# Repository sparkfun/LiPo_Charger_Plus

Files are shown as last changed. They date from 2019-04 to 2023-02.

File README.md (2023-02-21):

SparkFun LiPo Charger Plus
========================================

SparkFun LiPo Charger Plus

[*SparkFun LiPo Charger Plus (PRT-15217)*](https://www.sparkfun.com/products/15217)

The SparkFun LiPo Charger Plus is the souped-up power option in the SparkFun line of single-cell lithium polymer (LiPo) battery chargers. With this iteration, we've changed the input charge connector to USB-C and provided charge rate selection as well as optional thermal protection. Charge, power, and done LEDs clearly indicate the status of your charging process. This board can be used for any of the 2-pin JST connector single cell LiPo batteries we carry. 

With an input voltage between 3.75V-6V, the MCP73833 can charge up to a maximum rate of 1000mAh and provides two forms of thermal protection. An internal sensor maintains maximum charging rate until the die temperature of the IC reaches ~95°C; the charge controller will then reduce the charge rate to prevent overheating. The MCP73833 also has an optional input pin for an NTC (negative-temperature coefficient) thermistor, thus gating the battery against possible damage. 

Repository Contents
-------------------

* **/Hardware** - Eagle design files (.brd, .sch)

Documentation
--------------
* **[SparkFun Fritzing Part](https://github.com/sparkfun/Fritzing_Parts/blob/main/products/15217_sfe_LiPo_Charger_Plus.fzpz)** - Fritzing diagrams for SparkFun products.
* **[Hookup Guide](https://learn.sparkfun.com/tutorials/lipo-charger-plus-hookup-guide)** - Basic hookup guide for the SparkFun LiPo Charger Plus.

License Information
-------------------

This product is _**open source**_!

Please review the LICENSE.md file for license information.

If you have any questions or concerns on licensing, please contact technical support on our [SparkFun forums](https://forum.sparkfun.com/viewforum.php?f=152).

Distributed as-is; no warranty is given.

- Your friends at SparkFun.

_<COLLABORATION CREDIT>_

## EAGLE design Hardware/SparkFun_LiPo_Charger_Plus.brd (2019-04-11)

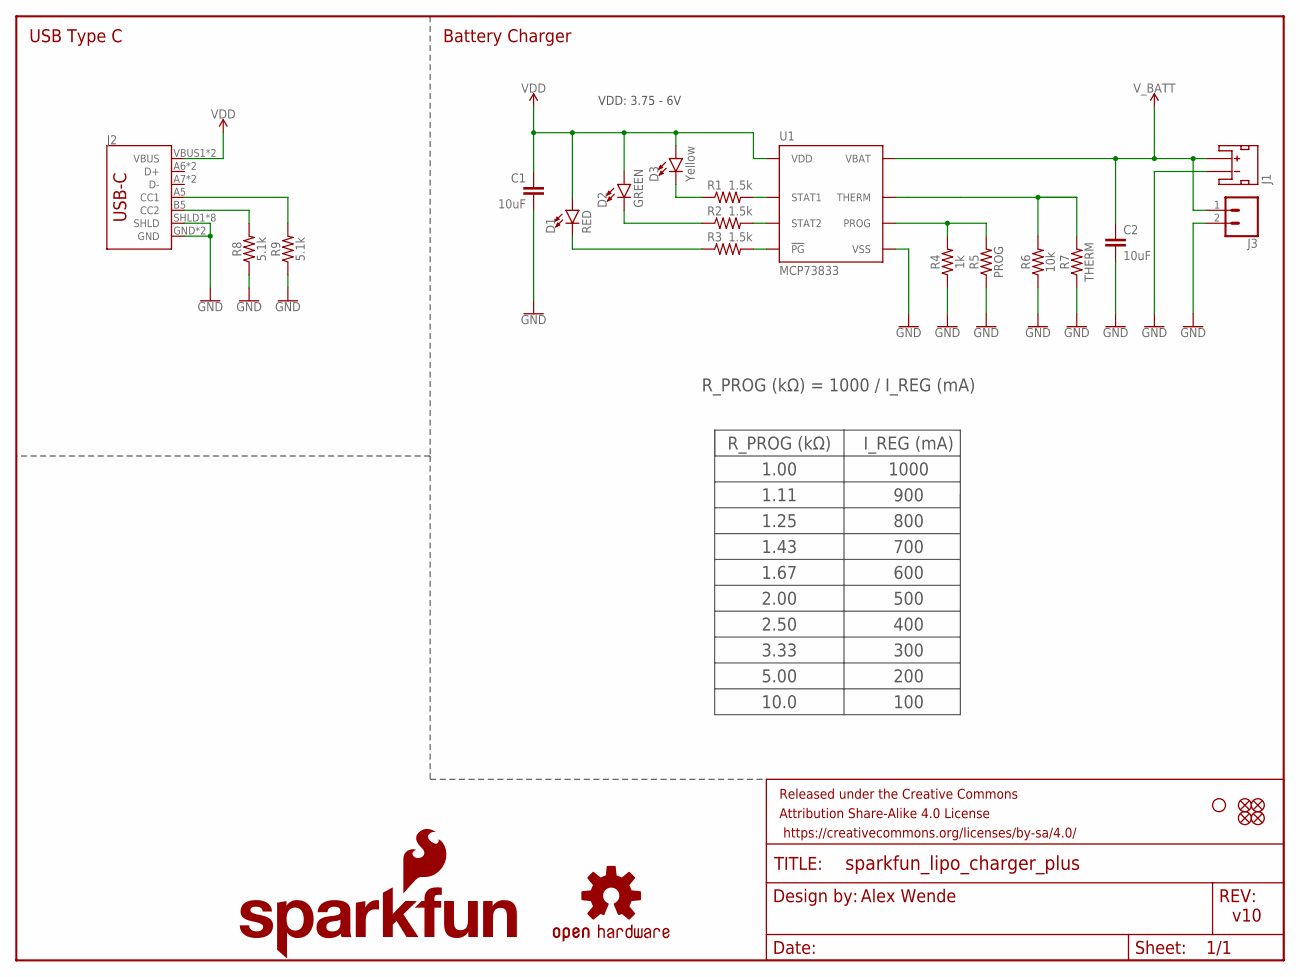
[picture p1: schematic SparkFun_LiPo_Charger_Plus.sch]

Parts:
C1, C2: 10uF; 0603
D1: RED; LED-0603
D2: GREEN; LED-0603
D3: Yellow; LED-0603
FD1, FD2, FD3, FD4: FIDUCIALUFIDUCIAL; FIDUCIAL-MICRO
FRAME1: FRAME-LETTER; CREATIVE_COMMONS
H1: STAND-OFF
J1: JST_2MM_MALE; JST-2-SMD
J2: USB_C16PIN; USB-C-16P
J3: CONN_021X02_NO_SILK; 1X02_NO_SILK
LOGO1: SFE_LOGO_NAME_FLAME.1_INCH; SFE_LOGO_NAME_FLAME_.1
LOGO2: OSHW-LOGOS; OSHW-LOGO-S
R1, R2, R3: 1.5k; 0603
R4: 1k; 0603
R5: PROG; AXIAL-0.3
R6: 10k; 0603
R7: THERM; AXIAL-0.3
R8, R9: 5.1k; 0603
U1: MCP73833; DFN-10

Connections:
GND: C1.2, C2.2, J1.1 (-), J2.GND, J2.GND2 (GND), J2.SHLD1 (SHLD), J2.SHLD2 (SHLD), J2.SHLD3 (SHLD), J2.SHLD4 (SHLD), J2.SHLD5 (SHLD), J2.SHLD6 (SHLD), J2.SHLD7 (SHLD), J2.SHLD8 (SHLD), J3.2, R4.1, R5.P$1 (1), R6.1, R7.P$1 (1), R8.1, R9.1, U1.P$5 (VSS), U1.P$11 (VSS)
unnamed: D1.C, R3.1
unnamed: D2.C, R2.1
unnamed: D3.C, R1.1
unnamed: J2.B5 (CC2), R8.2
unnamed: J2.A5 (CC1), R9.2
PG: R3.2, U1.P$7 (!PG)
PROG: R4.2, R5.P$2 (2), U1.P$6 (PROG)
STAT1: R1.2, U1.P$3 (STAT1)
STAT2: R2.2, U1.P$4 (STAT2)
THERM: R6.2, R7.P$2 (2), U1.P$8 (THERM)
VDD: C1.1, D1.A, D2.A, D3.A, J2.VBUS1 (VBUS), J2.VBUS2 (VBUS), U1.P$1 (VDD), U1.P$2 (VDD)
V_BATT: C2.1, J1.2 (+), J3.1, U1.P$9 (VBAT), U1.P$10 (VBAT)

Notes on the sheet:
USB Type C
Battery Charger
Alex Wende
v10
R_PROG (kΩ) = 1000 / I_REG (mA)
R_PROG (kΩ)
I_REG (mA)
1.00
1000
900
800
700
600
500
400
300
200
100
1.25
1.11
1.43
1.67
2.00
2.50
3.33
5.00
10.0
VDD: 3.75 - 6V

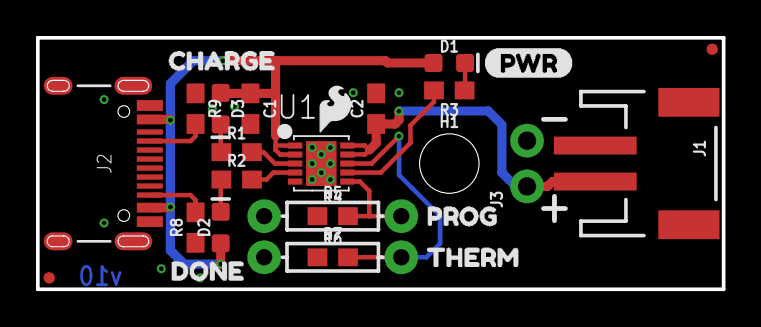
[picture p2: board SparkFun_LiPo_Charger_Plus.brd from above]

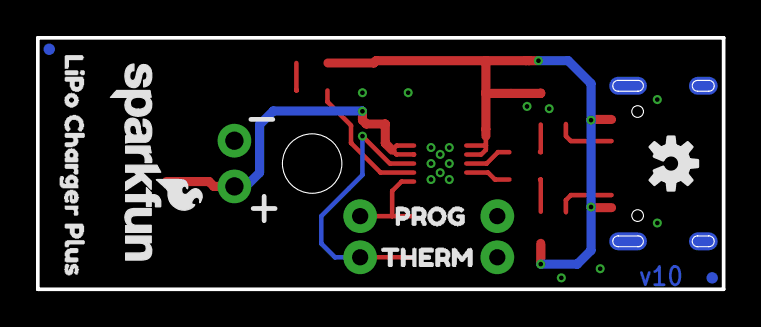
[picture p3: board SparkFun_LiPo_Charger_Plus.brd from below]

Board: 2 copper layers, 38.1 x 14.0 mm, 35 parts (7 on the bottom side), 13 nets.

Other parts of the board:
U$1: SFE_LOGO_FLAME_.1
U$2, U$5: PROG7
U$3: CHARGE3
U$4: DONE4
U$6, U$8: THERM8
U$7: PWR6
U$9: LIPO_CHARGER_PLUS0

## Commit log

2019-02-11 QC Fixes
    -Changed engineer text from measures layer to tDocu layer
    [LiPo Charger Plus.brd]
2019-04-10 v10 Update
    Added PROD_ID to U1, fixed part number ordering.
    [SparkFun_LiPo_Charger_Plus.brd, SparkFun_LiPo_Charger_Plus.sch]
2019-04-10 QC Fixes
    Adjusted bottom silk
    [SparkFun_LiPo_Charger_Plus.brd]
2019-04-11 Update SparkFun_LiPo_Charger_Plus.brd
    Moved bstop in a tiny bit
    [SparkFun_LiPo_Charger_Plus.brd]

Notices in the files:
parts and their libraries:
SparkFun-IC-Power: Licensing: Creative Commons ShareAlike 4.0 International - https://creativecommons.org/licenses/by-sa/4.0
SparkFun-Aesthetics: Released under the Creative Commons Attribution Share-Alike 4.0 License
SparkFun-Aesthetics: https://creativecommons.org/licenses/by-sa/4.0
